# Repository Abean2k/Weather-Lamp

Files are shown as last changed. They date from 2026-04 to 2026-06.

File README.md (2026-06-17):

# Weather-Lamp

WeatherLamp



A lamp with 5 RGB LED's that connects to the weather usign ESP32 to display the "mood" outside. Made for STASIS. 

## Assembly Guide
### Items you need (Besides the PCB and 3D Printed Parts):
2 M3 6mm-12mm screws
2 M4 6mm-12mm screws

First take the base and slide in the oled screen. Keep the wires up like in the picture so that they line up with the cutout in the base. 

Next use the 2 M3 screws to screw the base to the PCB. Make sure to keep the usb on the esp 32 facing the cutout. Also keep LEDs up.

Then prepare the top cover by glueing the the translusent petg crystle to the lip of the top cover usign super glue or hotglue. Be careful while handeling the crystle as 1 layered 3d prints are fragile. 

Finally, take the top cover with the crystle on it and screw it into the base with the 2 M4 screws. 


That's it, now just ubload firmware and you are good to go :)

## Design:
I wanted this lamp to be small and unique. This is why I choose to make a more difficult, but better looking crystal/geode lamp. I also wanted to have an OLED to convey the exact temperature which was something the rgb lamp could not. For the base of the design I tried to keep it as minimalist as possible, which led to it essentially wrapping around the circular pcb, with a flat front surface for the oled. 

The bottom two peices; bottom case, and top cover will be printed using pla in gray or black and the crystle will be a vase mode print with clear/transulcent PETG. PCB will be assembled by hand.  

## PCB:
I made my 2 layered pcb for this project on kicad. I choose to use a pcb for this project in order to keep the lamp internals neat and professional looking. The design of this pcb keeps the LEDs in a circle with one in the center and the microcontroller and capacitor on the back side. For the OLED a header allows me to connect and solder the wires to the pcb to the OLED while allowing the OLED to be in a different direction from my LEDs and microcontroller.

### Schematic
1776021340577-kuo91q

### PCB Layout
1776021296768-2o2wdi

## Firmware:
The firmware for this project was made in arduino in c++. It tells the microcontroller how to fetch data from OpenWeather and use the temperature and weather code data from that to light up the LEDs and display the temperature on the OLED in fahrenheit. 

#### How to Upload: Plug in usb through the large opening and upload through arudino ide.

## BOM:

Note: For items with more than my reqired amount it is due to min order limits.

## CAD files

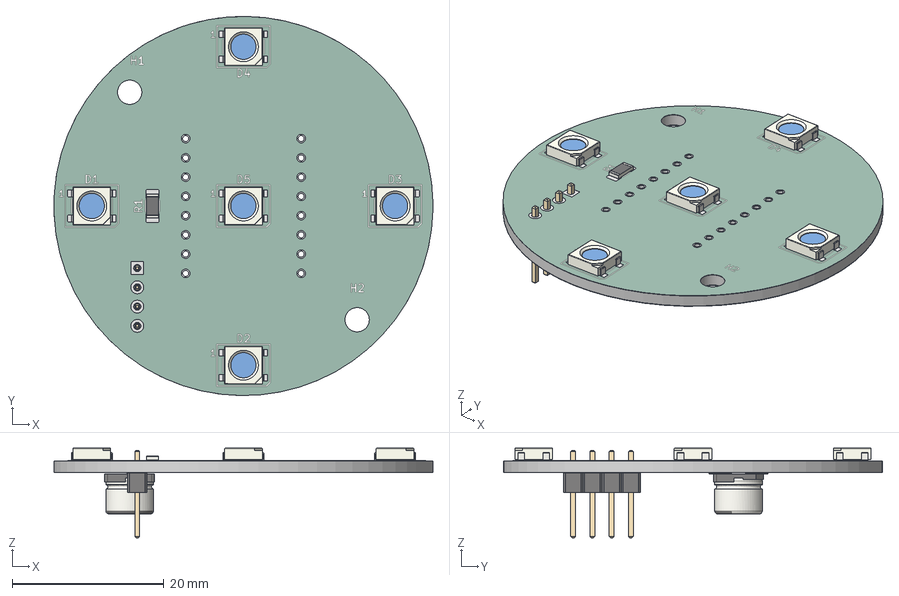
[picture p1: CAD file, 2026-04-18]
PCB/WeatherLamp.step
50.0 x 50.0 x 11.8 mm
LED_WS2812B_PLCC4_5.0x5.0mm_P3.2mm x 5
R_1206_3216Metric
CP_Elec_6.3x5.4
PinHeader_1x04_P2.54mm_Vertical
WeatherLamp_copper
WeatherLamp_pad
WeatherLamp_via
WeatherLamp_silkscreen x 2
WeatherLamp_soldermask x 2
WeatherLamp_PCB

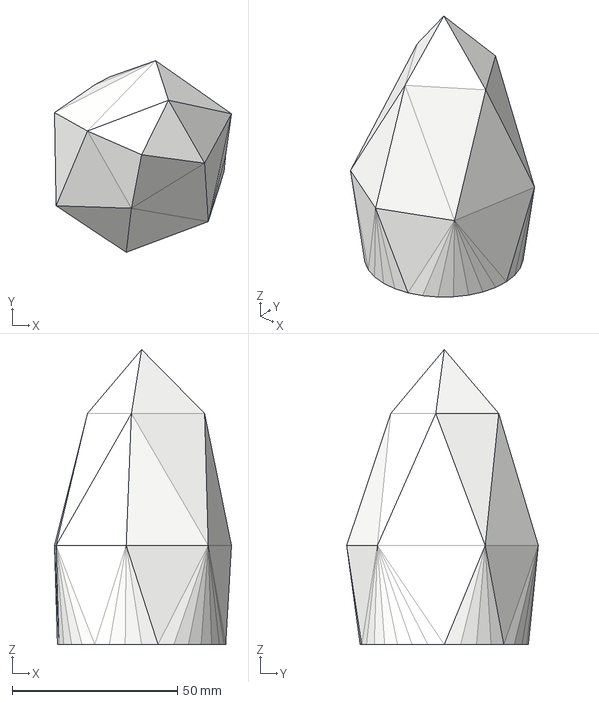
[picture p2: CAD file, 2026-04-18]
WeatherLampProduction/PartsToPrint/Geode - Copy.step
53.6 x 58.1 x 89.4 mm

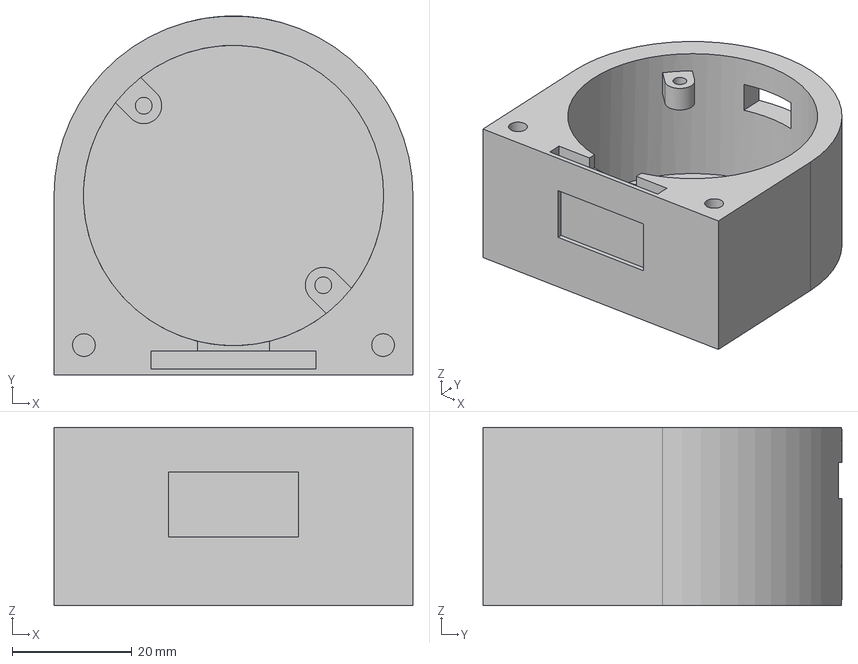
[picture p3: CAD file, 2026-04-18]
WeatherLampProduction/PartsToPrint/Stand_Bottom - Copy.step
60.0 x 60.0 x 29.8 mm

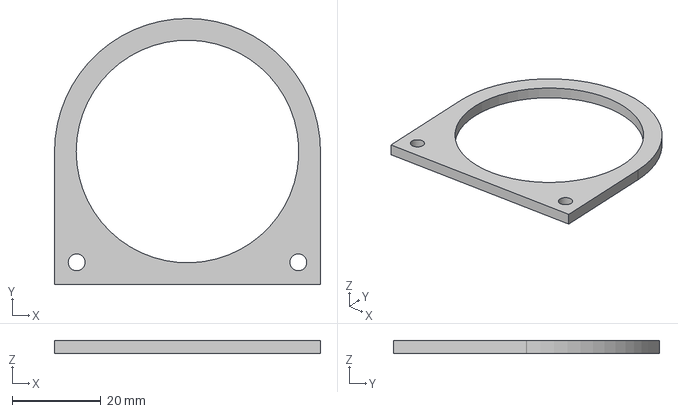
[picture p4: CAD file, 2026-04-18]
WeatherLampProduction/PartsToPrint/Stand_Top - Copy.step
60.0 x 60.0 x 3.00 mm

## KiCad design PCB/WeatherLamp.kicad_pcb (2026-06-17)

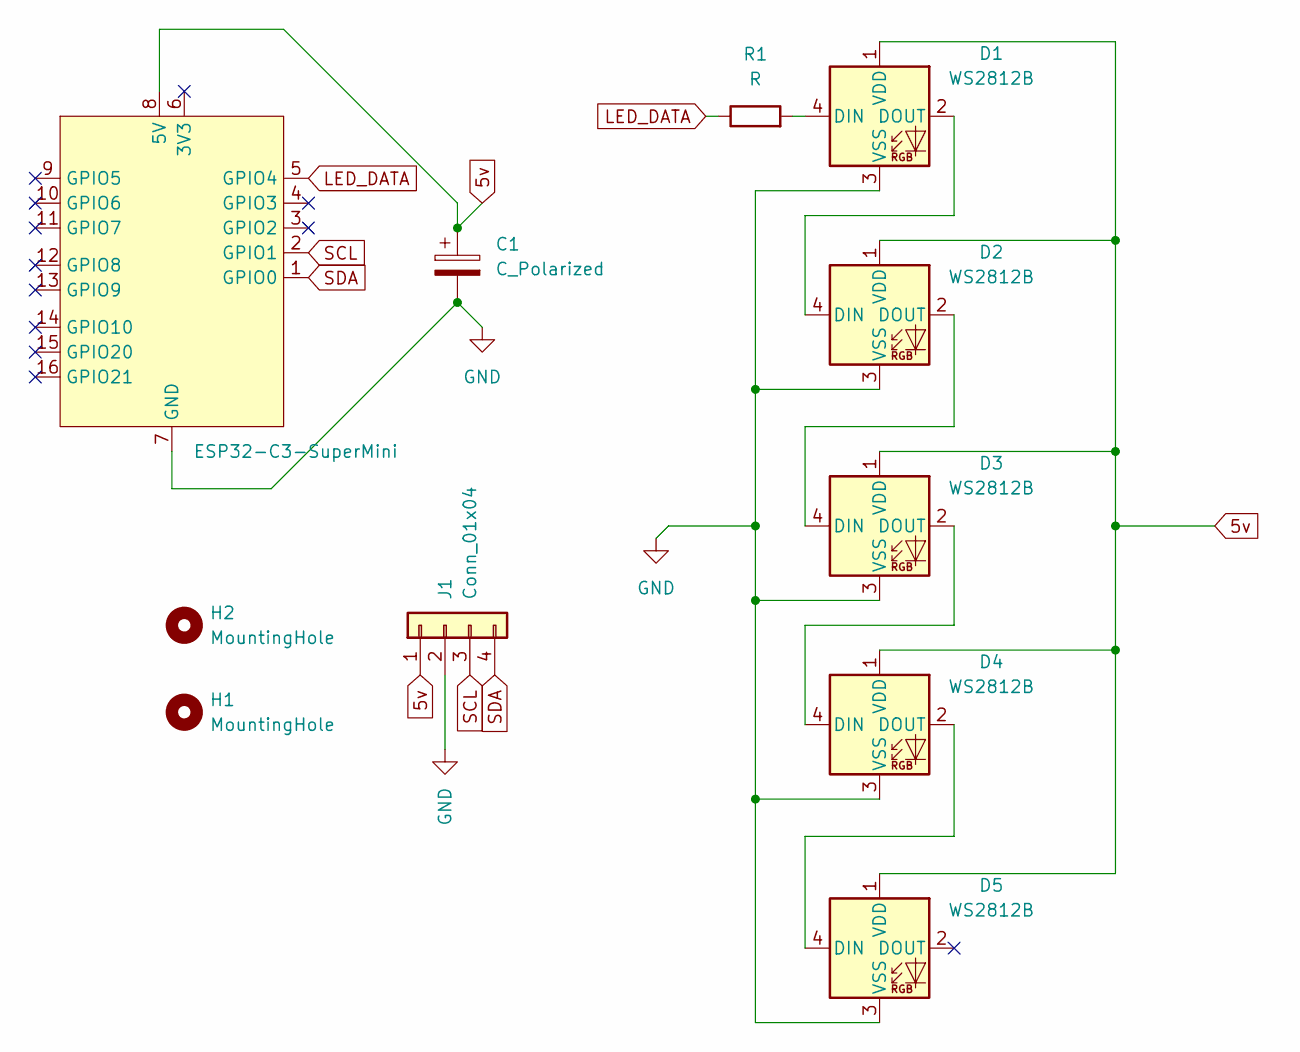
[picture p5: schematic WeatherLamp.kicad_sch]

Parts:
C1: C_Polarized; CP_Elec_6.3x5.4
D1, D2, D3, D4, D5: WS2812B; LED_WS2812B_PLCC4_5.0x5.0mm_P3.2mm
H1, H2: MountingHole; MountingHole_3.2mm_M3
J1: Conn_01x04; PinHeader_1x04_P2.54mm_Vertical
R1: R; R_1206_3216Metric_Pad1.30x1.75mm_HandSolder
U1: ESP32-C3-SuperMini

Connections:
5v: C1.1, D1.1 (VDD), D2.1 (VDD), D3.1 (VDD), D4.1 (VDD), D5.1 (VDD), J1.1, U1.8 (5V)
GND: C1.2, D1.3 (VSS), D2.3 (VSS), D3.3 (VSS), D4.3 (VSS), D5.3 (VSS), J1.2, U1.7 (GND)
LED_DATA: R1.1, U1.5 (GPIO4)
unnamed: D1.4 (DIN), R1.2
unnamed: D1.2 (DOUT), D2.4 (DIN)
unnamed: D2.2 (DOUT), D3.4 (DIN)
unnamed: D3.2 (DOUT), D4.4 (DIN)
unnamed: D4.2 (DOUT), D5.4 (DIN)
SCL: J1.3, U1.2 (GPIO1)
SDA: J1.4, U1.1 (GPIO0)

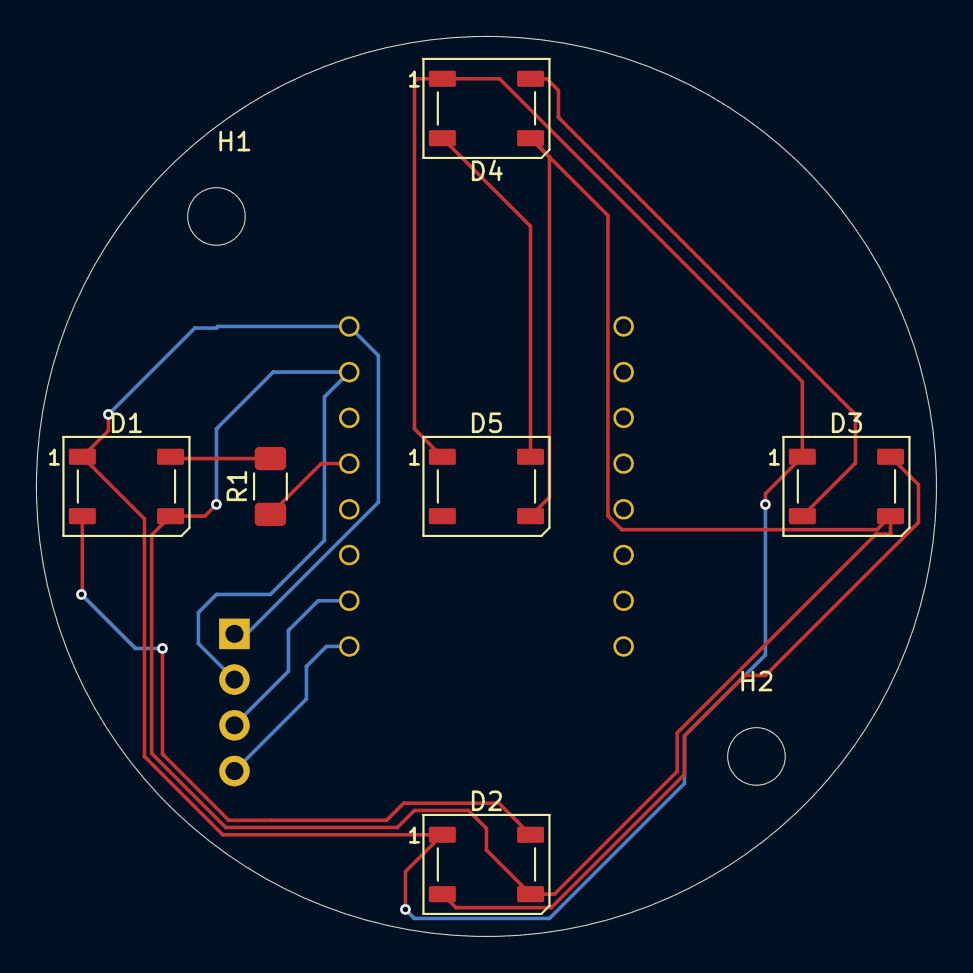
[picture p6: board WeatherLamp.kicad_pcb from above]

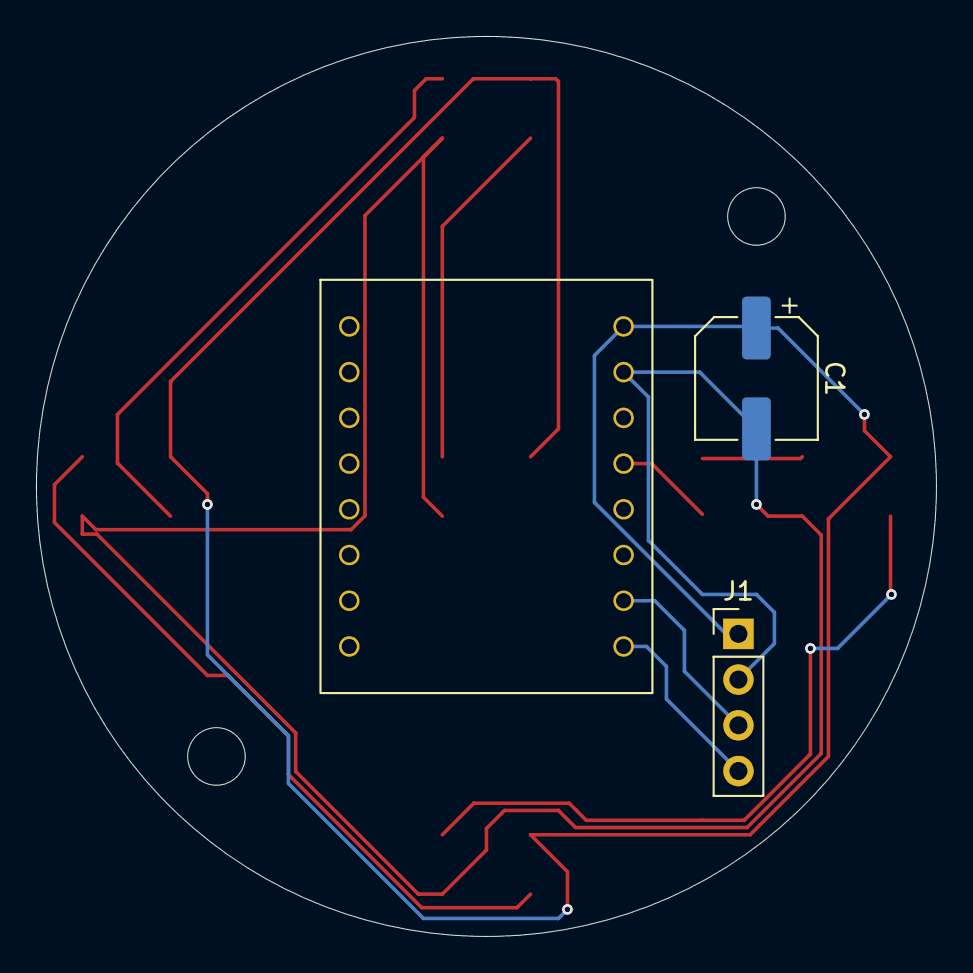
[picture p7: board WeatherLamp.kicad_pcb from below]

Board: 2 copper layers, 50.0 x 50.0 mm, 11 parts (3 on the bottom side), 10 nets.

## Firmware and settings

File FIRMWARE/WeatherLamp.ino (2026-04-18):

#include <ArduinoJson.h>  
#include <FastLED.h>     
#include <WiFi.h>         
#include <Wire.h>
#include <Adafruit_GFX.h>
#include <Adafruit_SSD1306.h>

#define SCREEN_WIDTH 128 
#define SCREEN_HEIGHT 64 
#define OLED_RESET    -1
#define NUM_LEDS 5
#define DATA_PIN 4

CRGB leds[NUM_LEDS];

Adafruit_SSD1306 display(SCREEN_WIDTH, SCREEN_HEIGHT, &Wire, OLED_RESET);

const char* ssid = "logos";                
const char* password = "aj_rocks!";                   
String APIKEY = "ccc6d2cd259d69e9f4de8feafc9ad66d";
String CityID = "4765691";         
bool id = false;
WiFiClient client;
char servername[] = "api.openweathermap.org";            
String result;


void setup() {
  Serial.begin(115200);


//led setup
  FastLED.addLeds<WS2812B, DATA_PIN, GRB>(leds, NUM_LEDS);
  FastLED.setBrightness(100);
  
//  Serial.print("Connecting to ");
  WiFi.mode(WIFI_STA);   //   create wifi station
 // Serial.println(ssid);
  WiFi.begin(ssid, password);

  Wire.begin(0, 1); // SDA = 0, SCL = 1
  display.begin(SSD1306_SWITCHCAPVCC, 0x3C);
  display.display();
  delay(200);
  display.clearDisplay();
  display.setTextSize(1);             // Normal 1:1 pixel scale
  display.setTextColor(SSD1306_WHITE, SSD1306_BLACK);        // Draw white text on black backround
  display.setCursor(0, 0);            // Start at top-left corner
  display.print("Connecting.");
  display.display();

  while (WiFi.status() != WL_CONNECTED) {
    delay(500);
 //   Serial.print(".");
    display.print(".");
    display.display();
  }

 // Serial.println("");
 // Serial.println("IP address: ");
  //Serial.println(WiFi.localIP());
  display.clearDisplay();
  display.setCursor(0, 0);
  display.println("Connected ");
  display.println("IP Address: ");
  display.println(WiFi.localIP());
  display.display();
  delay(1000);
  display.clearDisplay();

}

void loop()                    
{
  if (client.connect(servername, 80))
  { 
    client.println("GET /data/2.5/weather?id=" + CityID + "&units=metric&APPID=" + APIKEY);
    client.println("Host: api.openweathermap.org");
    client.println("User-Agent: ArduinoWiFi/1.1");
    client.println("Connection: close");
    client.println();
  }
  else {
    //Serial.println("connection failed");        
    //Serial.println();
    display.print("error: check serial port");
  }

  while (client.connected() && !client.available())
    delay(1);                                         
  while (client.connected() || client.available())
  { //connected or data available
    char c = client.read();                     
    result = result + c;
  }

  client.stop();                                    
  result.replace('[', ' ');
  result.replace(']', ' ');
  //Serial.println(result);
  char jsonArray [result.length() + 1];
  result.toCharArray(jsonArray, sizeof(jsonArray));
  jsonArray[result.length() + 1] = '\0';
  StaticJsonDocument<1024> doc;
  DeserializationError  error = deserializeJson(doc, jsonArray);


  if (error) {
   // Serial.print(F("deserializeJson() failed with code "));
   // Serial.println(error.c_str());
    display.print("error: check serial port");
    return;
  }

  String location = doc["name"];
  int temperature = doc["main"]["temp"];
  int humidity = doc["main"]["humidity"];
  int weatherId = doc["weather"][0]["id"];



/*   Serial.println();
  Serial.print("Country: ");
  Serial.println(country);
  Serial.print("Location: ");
  Serial.println(location);
  Serial.print("Location ID: ");
  Serial.println(id);
  Serial.printf("Temperature: %d°C\r\n", temperature);
  Serial.printf("Humidity: %d %%\r\n", humidity);
  Serial.printf("Pressure: %.2f hpa\r\n", pressure);
  Serial.printf("Wind speed: %.1f m/s\r\n", Speed);
  Serial.printf("Wind degree: %d°\r\n", degree);
  Serial.printf("Longitude: %.2f\r\n", longitude);
  Serial.printf("Latitude: %.2f\r\n", latitude); */
  
  display.clearDisplay();
  display.setCursor(0, 0);            // Start at top-left corner (will calibrate to make it centered once i have the parts)

  display.println();
  display.setTextColor(SSD1306_WHITE, SSD1306_BLACK);
  display.print("Temp(F): ");
  display.print((temperature - 273.15) * 9/5 + 32); // the fromula to change the kelvin into freedom units
  
  display.display();
  
  //LED LOGIC 

  //Note: I will change add add to these colors once I see how they acutally look on the final product. 
  if (weatherId >= 200 && weatherId < 300) {
    // 2xx = Thunderstorm: Purple
    setGeoidColor(150, 0, 255); 
  } else if (weatherId >= 300 && weatherId < 600) {
    // 3xx & 5xx = Rain:  Blue
    setGeoidColor(0, 0, 255);
  } else if (weatherId == 800) {
    // 800 = Clear:  Warm Orange/Yellow
    setGeoidColor(255, 100, 0);
  } else {
    // Default for Clouds/Mist: White
    setGeoidColor(100, 100, 100);
  }


  delay(600000);     // 10 min delay

}

//made a function to make setting colors easier
void setGeoidColor(int r, int g, int b) {
  for(int i = 0; i < NUM_LEDS; i++) {
    leds[i] = CRGB(r, g, b);
  }
  FastLED.show();
}

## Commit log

2026-04-18 Most Files Added
    [WeatherLamp.kicad_pcb, WeatherLamp.kicad_sch, WeatherLamp.step]
2026-04-18 Added parts to print
    [Geode.step, Stand_Bottom.step, Stand_Top.step]
2026-04-18 Expand README with project details and images
    Added detailed sections on design, PCB, firmware, and BOM.
2026-04-24 Enhance README with assembly guide and project details
    Added assembly guide and details for the WeatherLamp project, including required items and assembly steps. Updated project description for clarity.
2026-06-17 Build Commit
    [WeatherLamp.kicad_pcb]
